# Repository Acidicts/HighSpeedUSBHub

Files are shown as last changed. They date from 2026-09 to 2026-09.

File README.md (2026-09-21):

# HighSpeedUSBHub

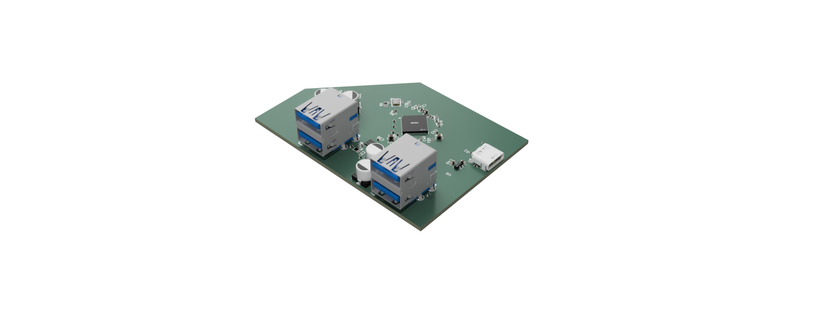
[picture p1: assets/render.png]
RENDER


I looked at an old USB 2.0 hub I made and though what if I could make a faster one? So I did(whether it works or not is another story). This started right after I discovered the [texas instruments](https://www.ti.com/) site via the guide for making a flight controller by @notaroomba.

This is a USB 3.1 hub which uses a usb 3.1 gen 2 upstream port to 4 usb 3.0 downstream ports via a [`TUSB8041`](https://www.ti.com/product/TUSB8041). Each USB stack (I used x2 stacked usb 3.0 ports as they were more compact, and they reminded me of the raspberry pi 4) is powered by a [`TPS2051B`](https://www.ti.com/product/TPS2051B) which is a power switch that has a power limit of around 1A per controller as I recall.

### Features
- 4 USB-A 3.0 downstream ports
- 1 USB-C 3.1 gen 2 upstream port
- Powered by the USB-C port (5V 3A)
- Each downstream port is limited to 1A of current and with equal load across each port, 0.5A per port.
- CRYSTAL 24MHz clock for the TUSB8041

<div class="inline-flex">
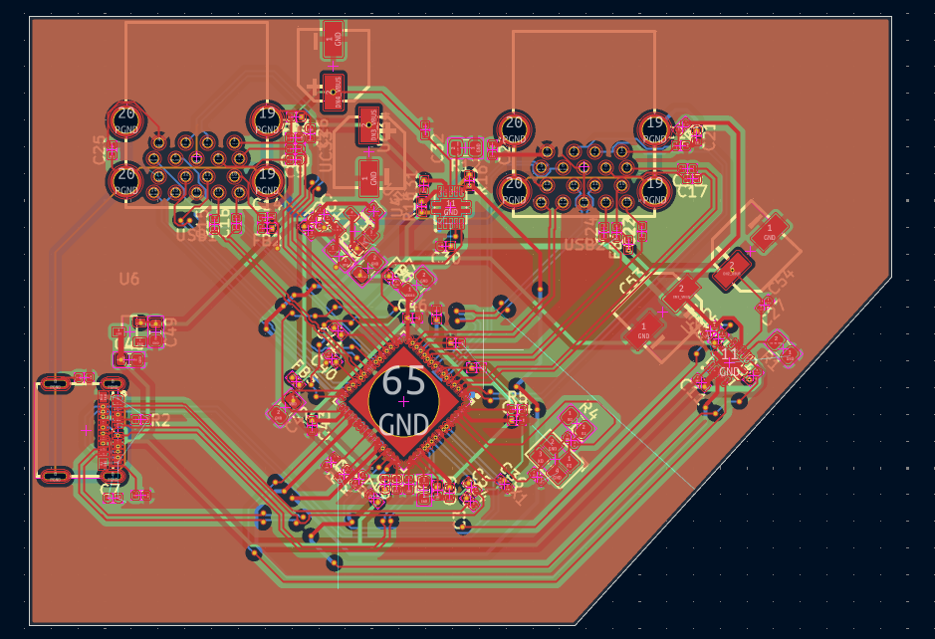
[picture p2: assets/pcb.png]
PCB

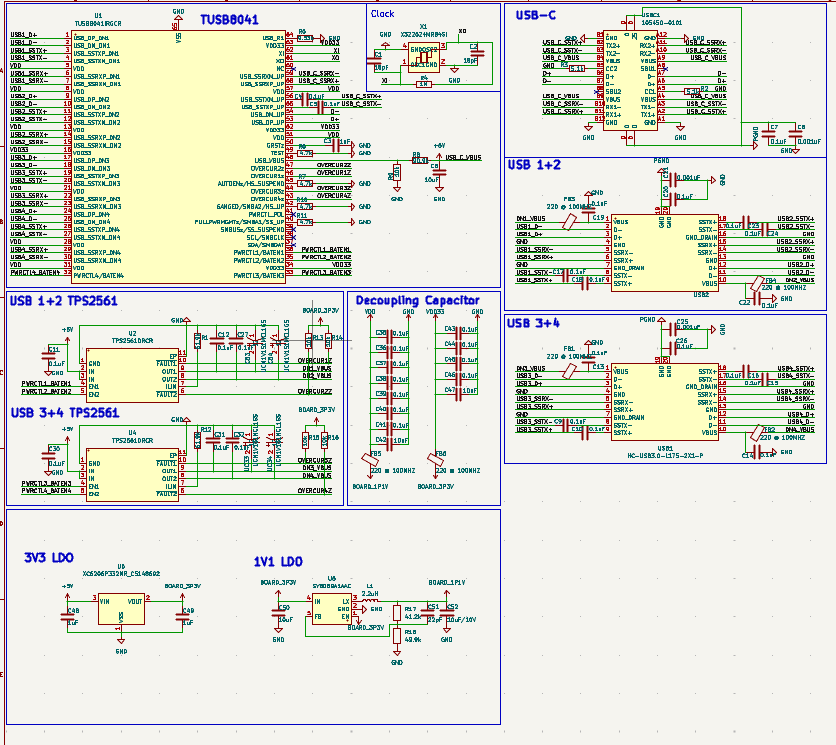
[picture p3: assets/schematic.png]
Schematic

</div>

### Case
Fusion 360 Link [here](https://a360.co/4czpJdL)
There are two parts of the case:
- The [Lid](case/Lid.stp)
- The [Base](case/Base.stp)
The lid has notches which slot into the base to hold it on using the power of friendship and friction.



### Getting Started
So ummm, how do I put this...

_*YOU PLUG IT IN*_

### Firmware
Sooo you won't believe this but it is just a usb hub, it is plug and play

### BOMs
- [BOM](BOM.csv)
- [PCB BOM](PCB_BOM.csv)

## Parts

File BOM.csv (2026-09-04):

What | Cost | Link
PCB | $7.00 | jlcpcb.com
PCBA | $84.89 | jlcpcb.com
Shipping | $11.88 | jlcpcb.com

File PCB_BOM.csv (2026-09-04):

Part Name, | Manufacturer/Type, | Designator, | Quantity, | Supplier, | Attrition Type, | LCSC Part#, | Unit Price, | Source
TUSB8041IRGCR, | Texas Instruments, | U1, | 2, | JLCPCB, | Extended, | C544686, | $4.0565, | [LCSC](https://www.lcsc.com/product-detail/C544686.html)
0402WGF4701TCE, | UNI-ROYAL (Uniroyal Elec), | R10,R11,R6,R7, | 8, | JLCPCB, | Basic, | C25900, | $0.0029, | [LCSC](https://www.lcsc.com/product-detail/C25900.html)
0402WGF1002TCE, | UNI-ROYAL (Uniroyal Elec), | R13,R14,R15,R16,R9, | 10, | JLCPCB, | Basic, | C25744, | $0.0031, | [LCSC](https://www.lcsc.com/product-detail/C25744.html)
XC6206P332MR, | HXY (MOSFET), | U6, | 10, | JLCPCB, | Extended, | C5148692, | $0.0182, | [LCSC](https://www.lcsc.com/product-detail/C5148692.html)
ARG05BTC6192, | Viking Tech, | R1,R12, | 8, | JLCPCB, | Extended, | C2984460, | $0.0290, | [LCSC](https://www.lcsc.com/product-detail/C2984460.html)
SMNR4020-2.2UH, | SXN (Shun Xiang Nuo Elec), | L1, | 6, | JLCPCB, | Extended, | C135262, | $0.0584, | [LCSC](https://www.lcsc.com/product-detail/C135262.html)
CR0402FF4122G, | LIZ Elec, | R17, | 20, | JLCPCB, | Extended, | C100420, | $0.0049, | [LCSC](https://www.lcsc.com/product-detail/C100420.html)
0805W8F1004T5E, | UNI-ROYAL (Uniroyal Elec), | R4, | 2, | JLCPCB, | Basic, | C17514, | $0.0047, | [LCSC](https://www.lcsc.com/product-detail/C17514.html)
CL05A106MQ5NUNC, | Samsung Electro-Mechanics, | C6, | 2, | JLCPCB, | Basic, | C15525, | $0.0256, | [LCSC](https://www.lcsc.com/product-detail/C15525.html)
0402CG220J500NT, | FH (Guangdong Fenghua Advanced Tech), | C51, | 2, | JLCPCB, | Basic, | C1555, | $0.0053, | [LCSC](https://www.lcsc.com/product-detail/C1555.html)
X322524MRB4SI, | YXC (Crystal Oscillators), | X1, | 6, | JLCPCB, | Extended, | C70571, | $0.1105, | [LCSC](https://www.lcsc.com/product-detail/C70571.html)
0402CG180J500NT, | FH (Guangdong Fenghua Advanced Tech), | C1,C2, | 4, | JLCPCB, | Basic, | C1549, | $0.0048, | [LCSC](https://www.lcsc.com/product-detail/C1549.html)
GRM21BR61H106KE43L, | Murata Electronics, | C42,C47,C50, | 6, | JLCPCB, | Basic, | C440198, | $0.2493, | [LCSC](https://www.lcsc.com/product-detail/C440198.html)
CL05B104KO5NNNC, | Samsung Electro-Mechanics, | C10,C11,C12,C13,C14,C15,C16,C17,C18,C19,C20,C22,C23,C24,C26,C27,C30,C31,C32,C35,C36,C37,C38,C39,C4,C40,C41,C43,C44,C45,C46,C5,C7,C9, | 68, | JLCPCB, | Basic, | C1525, | $0.0051, | [LCSC](https://www.lcsc.com/product-detail/C1525.html)
RC0402FR-0790K9L, | YAGEO, | R8, | 20, | JLCPCB, | Extended, | C163452, | $0.0039, | [LCSC](https://www.lcsc.com/product-detail/C163452.html)
0402WGF5101TCE, | UNI-ROYAL (Uniroyal Elec), | R2,R3, | 4, | JLCPCB, | Basic, | C25905, | $0.0026, | [LCSC](https://www.lcsc.com/product-detail/C25905.html)
UCM1V151MCL1GS, | Nichicon, | C53,C54,UC33,UC34, | 8, | JLCPCB, | Extended, | C729687, | $0.3816, | [LCSC](https://www.lcsc.com/product-detail/C729687.html)
BLM15PX221SN1D, | Murata Electronics, | FB1,FB2,FB3,FB4,FB5,FB6, | 22, | JLCPCB, | Extended, | C160973, | $0.0174, | [LCSC](https://www.lcsc.com/product-detail/C160973.html)
0402WGF9531TCE, | UNI-ROYAL (Uniroyal Elec), | R5, | 20, | JLCPCB, | Extended, | C96273, | $0.0026, | [LCSC](https://www.lcsc.com/product-detail/C96273.html)
TPS2561DRCR, | Texas Instruments, | U2,U4, | 4, | JLCPCB, | Extended, | C140303, | $1.4036, | [LCSC](https://www.lcsc.com/product-detail/C140303.html)
0402B102K500NT, | FH (Guangdong Fenghua Advanced Tech), | C21,C25,C8, | 6, | JLCPCB, | Basic, | C1523, | $0.0060, | [LCSC](https://www.lcsc.com/product-detail/C1523.html)
CL10A105KB8NNNC, | Samsung Electro-Mechanics, | C3,C48,C49, | 6, | JLCPCB, | Basic, | C15849, | $0.0058, | [LCSC](https://www.lcsc.com/product-detail/C15849.html)
0603WAF4992T5E, | UNI-ROYAL (Uniroyal Elec), | R18, | 2, | JLCPCB, | Basic, | C23184, | $0.0047, | [LCSC](https://www.lcsc.com/product-detail/C23184.html)
1054500101, | MOLEX, | USBC1, | 2, | JLCPCB, | Extended, | C134092, | $0.8399, | [LCSC](https://www.lcsc.com/product-detail/C134092.html)
SY8089A1AAC, | Silergy Corp, | U5, | 6, | JLCPCB, | Extended, | C479074, | $0.0879, | [LCSC](https://www.lcsc.com/product-detail/C479074.html)
CL05A106MP5NUNC, | Samsung Electro-Mechanics, | C52, | 20, | JLCPCB, | Extended, | C315248, | $0.0324, | [LCSC](https://www.lcsc.com/product-detail/C315248.html)
HC-USB3.0-L175-2X1-P, | Hong Cheng, | USB1,USB2, | 4, | JLCPCB, | Extended, | C7501881, | $0.3107, | [LCSC](https://www.lcsc.com/product-detail/C7501881.html)

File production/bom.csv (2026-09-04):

Designator | Footprint | Quantity | Value | LCSC Part #
C1, C2 | 0402 | 2 | 18pF
C10, C11, C12, C13, C14, C15, C16, C17, C18, C19, C20, C22, C23, C24, C26, C27, C30, C31, C32, C35, C36, C37, C38, C39, C4, C40, C41, C43, C44, C45, C46, C5, C7, C9 | 0402 | 34 | 0.1uF
C21, C25, C8 | 0402 | 3 | 0.001uF
C3, C48, C49 | 0603 | 3 | 1uF
C42, C47, C50 | 0805 | 3 | 10uF
C51 | 0402 | 1 | 22pF
C52 | 0402 | 1 | 10uF/10V
C53, C54, UC33, UC34 | CAP-SMD_L6.6-W6.6 | 4 | UCM1V151MCL1GS | C729687
C6 | 0402 | 1 | 10uF
FB1, FB2, FB3, FB4, FB5, FB6 | 0402 | 6 | 220 @ 100MHZ
L1 | L_Coilcraft_0403HQ_1008Metric | 1 | 2.2uH
R1, R12 | 0805 | 2 | 61.9k
R10, R11, R6, R7 | 0402 | 4 | 4.7k
R13, R14, R15, R16, R9 | 0402 | 5 | 10k
R17 | 0402 | 1 | 41.2k
R18 | 0603 | 1 | 49.9k
R2, R3 | 0402 | 2 | 5.1k
R4 | 0805 | 1 | 1M
R5 | 0402 | 1 | 9.53k
R8 | 0402 | 1 | 90.9k
U1 | QFN-64_L9.0-W9.0-P0.50-BL-EP7.2 | 1 | TUSB8041IRGCR | C544686
U2, U4 | VSON-10_L3.0-W3.0-P0.50-TL-EP_TPS62410DRCR | 2 | TPS2561DRCR | C140303
U5 | TSOT-23-5_L2.9-W1.6-P0.95-LS2.8-BR | 1 | SY8089A1AAC | C479074
U6 | SOT-23-3_L2.9-W1.3-P1.90-LS2.4-BR | 1 | XC6206P332MR_C5148692 | C5148692
USB1, USB2 | USB-A-TH_H181-AF2R06-12ALCR | 2 | HC-USB3.0-L175-2X1-P | C7501881
USBC1 | USB-C-SMD_TYPE-C-USB-18 | 1 | 105450-0101 | C134092
X1 | CRYSTAL-SMD_4P-L3.2-W2.5-BL-2 | 1 | X322524MRB4SI | C70571

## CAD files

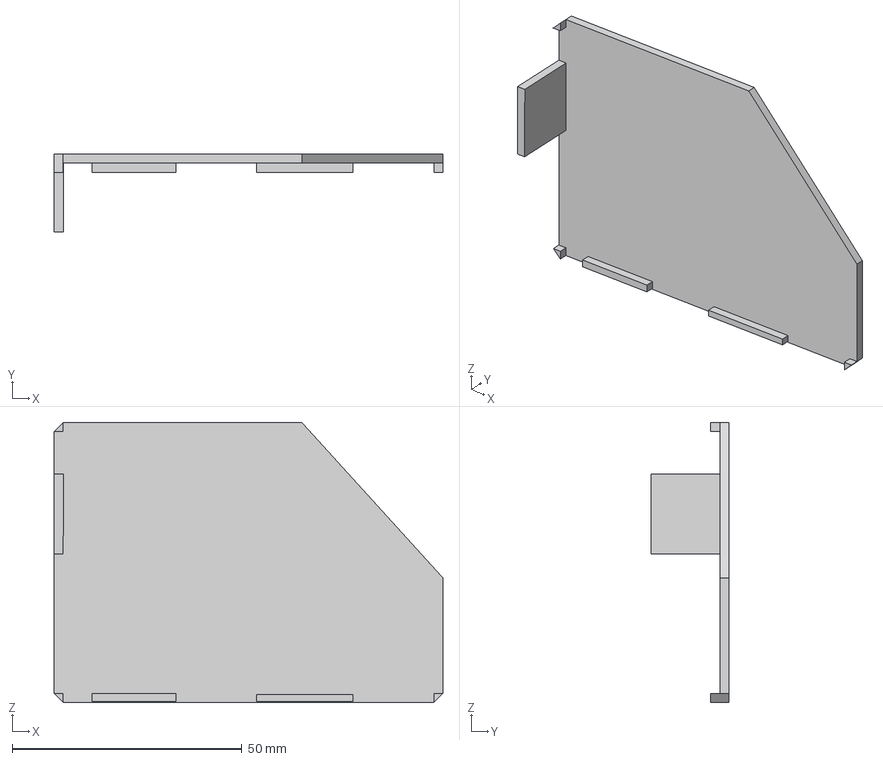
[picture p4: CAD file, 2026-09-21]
case/Lid.stp
84.6 x 17.0 x 61.0 mm

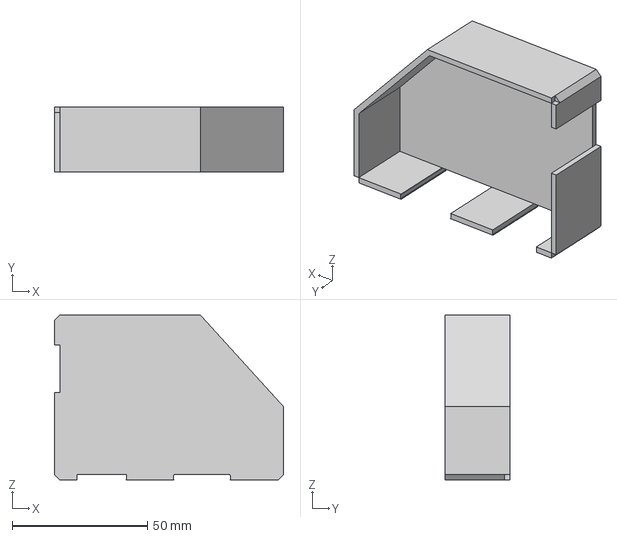
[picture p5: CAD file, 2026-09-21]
case/Base.stp
84.6 x 24.0 x 61.0 mm

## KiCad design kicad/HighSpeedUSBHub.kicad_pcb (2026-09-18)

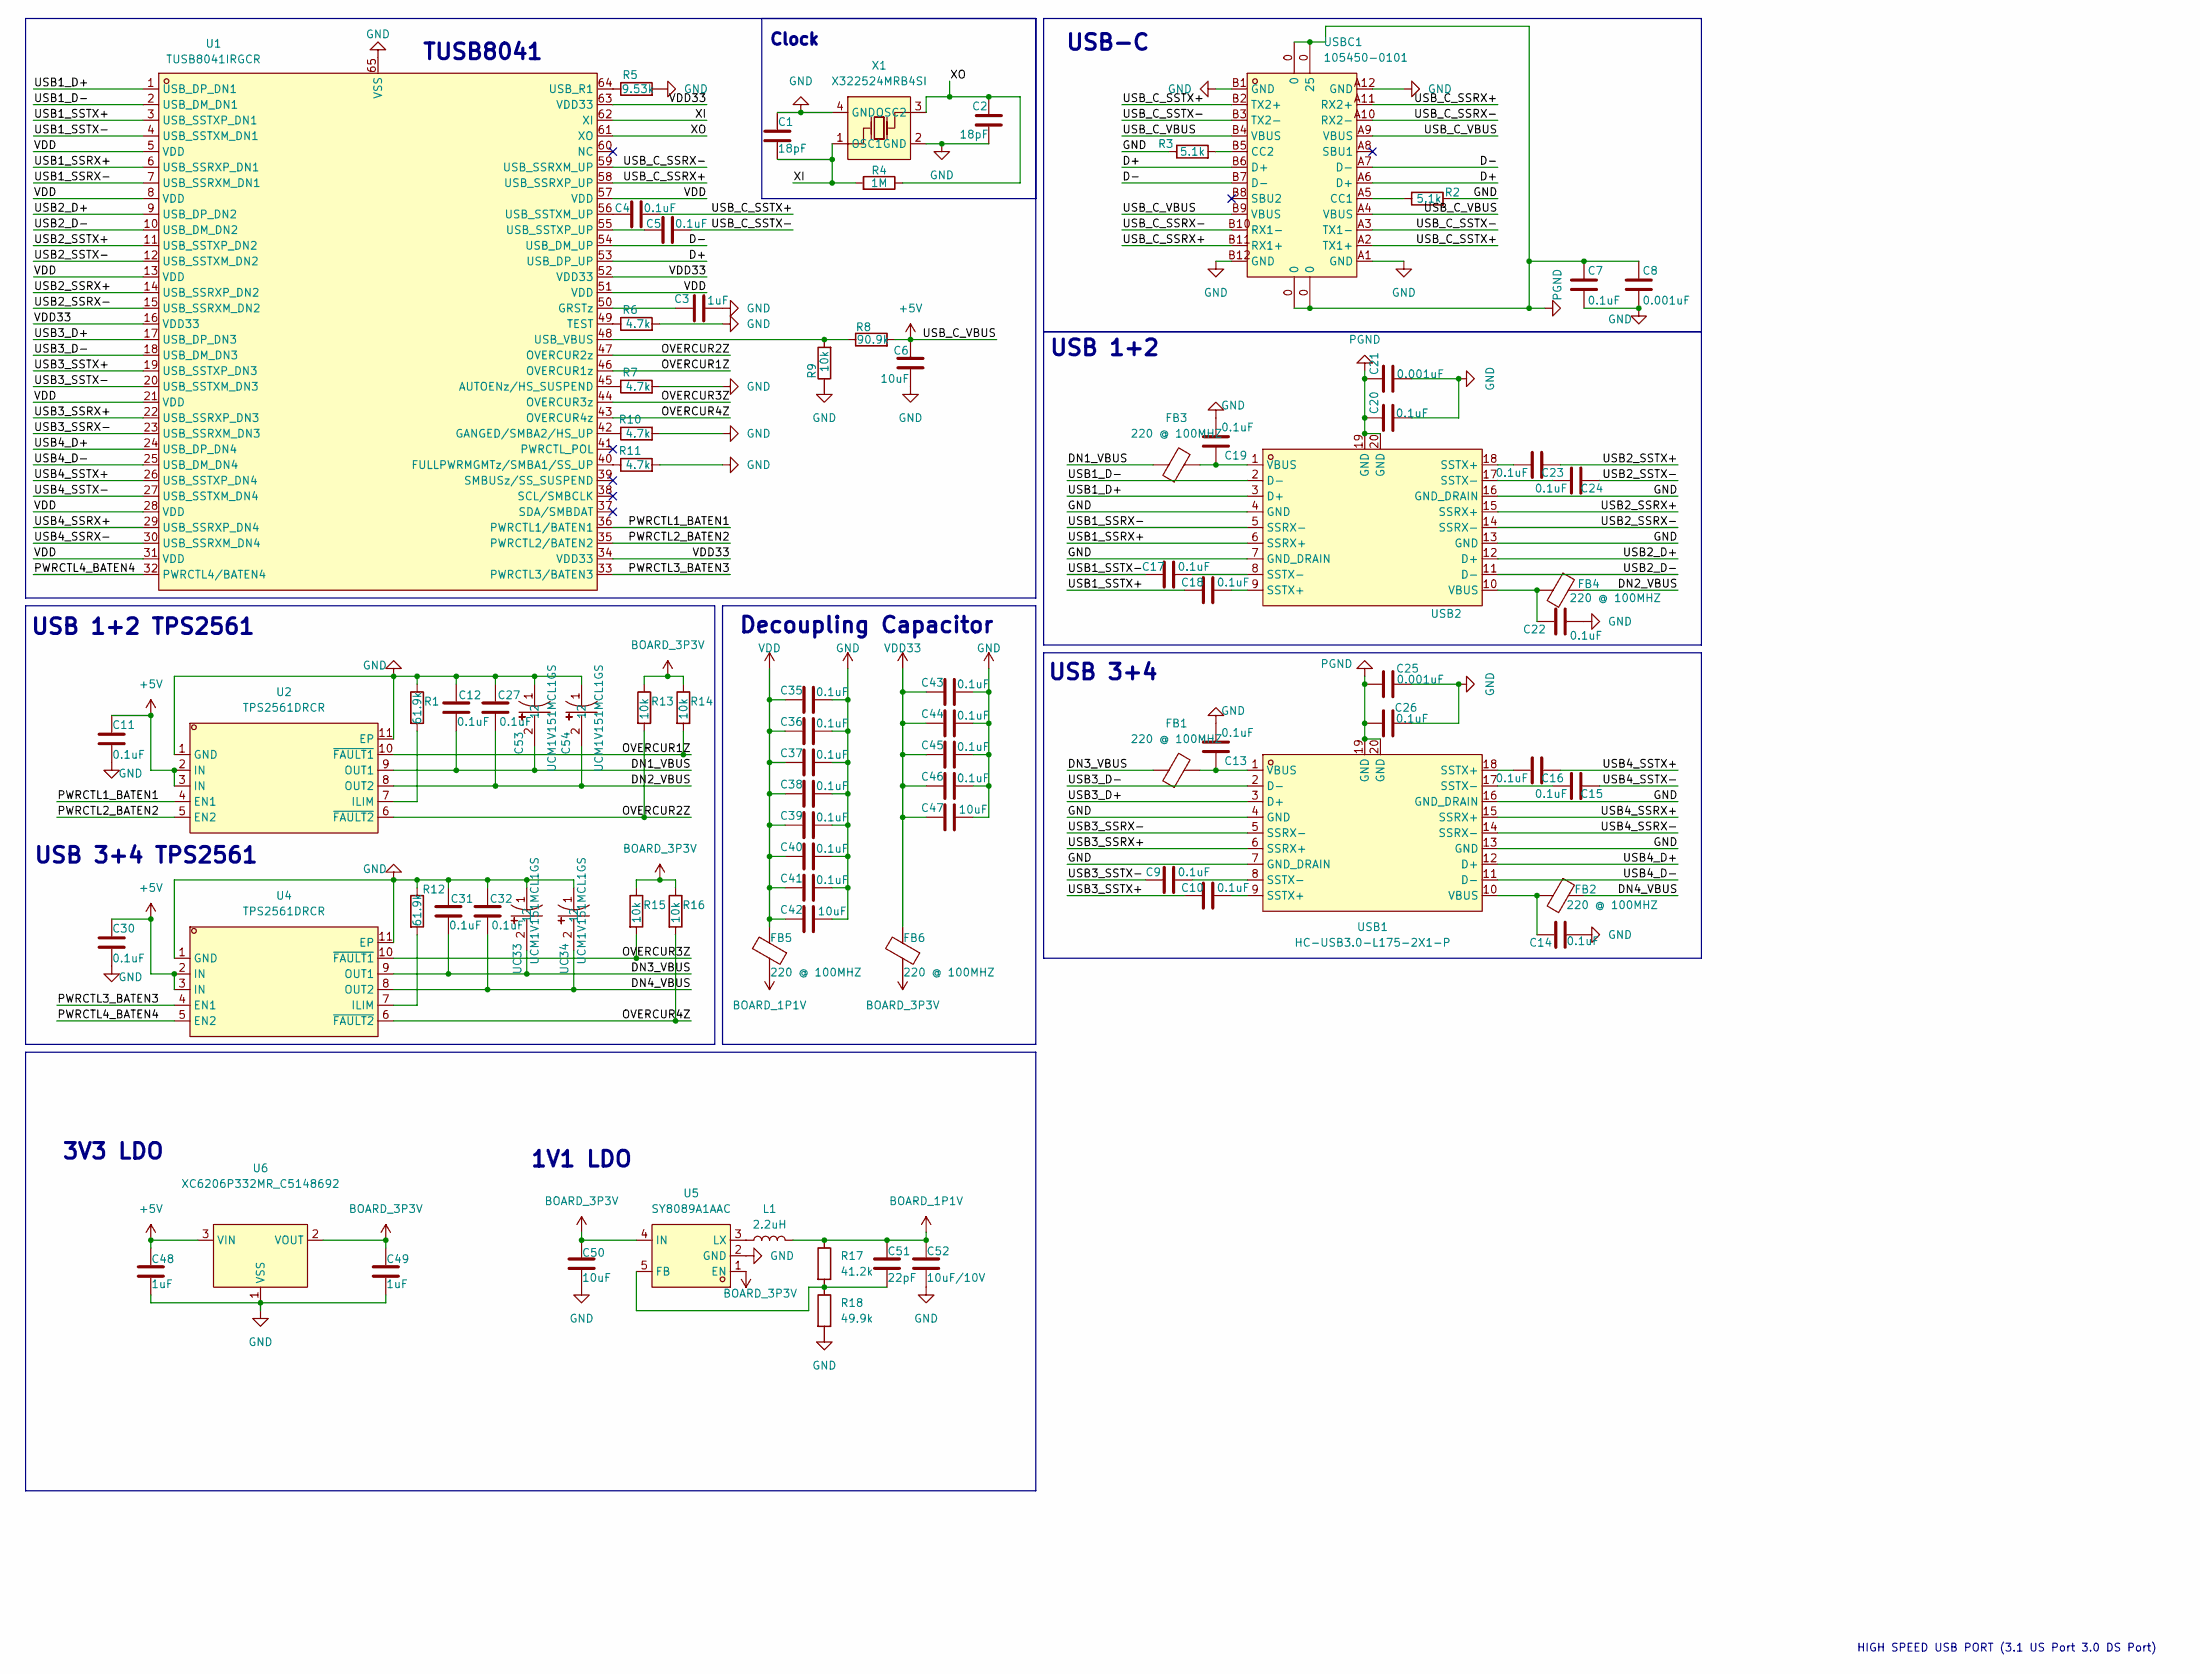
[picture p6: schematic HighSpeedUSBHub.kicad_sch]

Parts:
C1, C2: 18pF; C_0402_1005Metric
C3, C48, C49: 1uF; C_0603_1608Metric
C4, C5, C7, C9, C10, C11, C12, C13, C14, C15, C16, C17, C18, C19, C20, C22, C23, C24, C26, C27, C30, C31, C32, C35, C36, C37, C38, C39, C40, C41, C43, C44, C45, C46: 0.1uF; C_0402_1005Metric
C6: 10uF; C_0402_1005Metric
C8, C21, C25: 0.001uF; C_0402_1005Metric
C42, C47, C50: 10uF; C_0805_2012Metric
C51: 22pF; C_0402_1005Metric
C52: 10uF/10V; C_0402_1005Metric
C53, C54: UCM1V151MCL1GS; CAP-SMD_L6.6-W6.6; MPN UCM1V151MCL1GS; LCSC Part C729687
FB1, FB2, FB3, FB4, FB5, FB6: 220 @ 100MHZ; C_0402_1005Metric
L1: 2.2uH; L_Coilcraft_0403HQ_1008Metric
R1, R12: 61.9k; R_0805_2012Metric
R2, R3: 5.1k; R_0402_1005Metric
R4: 1M; R_0805_2012Metric
R5: 9.53k; R_0402_1005Metric
R6, R7, R10, R11: 4.7k; R_0402_1005Metric
R8: 90.9k; R_0402_1005Metric
R9, R13, R14, R15, R16: 10k; R_0402_1005Metric
R17: 41.2k; R_0402_1005Metric
R18: 49.9k; R_0603_1608Metric
U1: TUSB8041IRGCR; QFN-64_L9.0-W9.0-P0.50-BL-EP7.2; MPN TUSB8041IRGCR; LCSC Part C544686
U2, U4: TPS2561DRCR; VSON-10_L3.0-W3.0-P0.50-TL-EP_TPS62410DRCR; MPN TPS2561DRCR; LCSC Part C140303
U5: SY8089A1AAC; TSOT-23-5_L2.9-W1.6-P0.95-LS2.8-BR; MPN SY8089A1AAC; LCSC Part C479074
U6: XC6206P332MR_C5148692; SOT-23-3_L2.9-W1.3-P1.90-LS2.4-BR; MPN XC6206P332MR; LCSC Part C5148692
UC33, UC34: UCM1V151MCL1GS; CAP-SMD_L6.6-W6.6; MPN UCM1V151MCL1GS; LCSC Part C729687
USB1, USB2: HC-USB3.0-L175-2X1-P; USB-A-TH_H181-AF2R06-12ALCR; MPN HC-USB3.0-L175-2X1-P; LCSC Part C7501881
USBC1: 105450-0101; USB-C-SMD_TYPE-C-USB-18; MPN 1054500101; LCSC Part C134092
X1: X322524MRB4SI; CRYSTAL-SMD_4P-L3.2-W2.5-BL-2; MPN X322524MRB4SI; LCSC Part C70571

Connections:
+5V: C6.2, C11.1, C30.1, C48.1, R8.2, U2.2 (IN), U2.3 (IN), U4.2 (IN), U4.3 (IN), U6.3 (VIN), USBC1.A4 (VBUS), USBC1.A9 (VBUS), USBC1.B4 (VBUS), USBC1.B9 (VBUS)
/D+: U1.53 (USB_DP_UP), USBC1.A6 (D+), USBC1.B6 (D+)
/D-: U1.54 (USB_DM_UP), USBC1.A7 (D-), USBC1.B7 (D-)
/DN1_VBUS: C12.2, C53.2, FB3.1, U2.9 (OUT1)
/DN2_VBUS: C27.2, C54.2, FB4.1, U2.8 (OUT2)
/DN3_VBUS: C31.2, FB1.1, U4.9 (OUT1), UC33.2
/DN4_VBUS: C32.2, FB2.1, U4.8 (OUT2), UC34.2
/OVERCUR1Z: R14.2, U1.46 (OVERCUR1z), U2.10 (~FAULT1)
/OVERCUR2Z: R13.2, U1.47 (OVERCUR2z), U2.6 (~FAULT2)
/OVERCUR3Z: R15.2, U1.44 (OVERCUR3z), U4.10 (~FAULT1)
/OVERCUR4Z: R16.2, U1.43 (OVERCUR4z), U4.6 (~FAULT2)
/PWRCTL1_BATEN1: U1.36 (PWRCTL1/BATEN1), U2.4 (EN1)
/PWRCTL2_BATEN2: U1.35 (PWRCTL2/BATEN2), U2.5 (EN2)
/PWRCTL3_BATEN3: U1.33 (PWRCTL3/BATEN3), U4.4 (EN1)
/PWRCTL4_BATEN4: U1.32 (PWRCTL4/BATEN4), U4.5 (EN2)
/USB1_D+: U1.1 (USB_DP_DN1), USB2.3 (D+)
/USB1_D-: U1.2 (USB_DM_DN1), USB2.2 (D-)
/USB1_SSRX+: U1.6 (USB_SSRXP_DN1), USB2.6 (SSRX+)
/USB1_SSRX-: U1.7 (USB_SSRXM_DN1), USB2.5 (SSRX-)
/USB1_SSTX+: C18.1, U1.3 (USB_SSTXP_DN1)
/USB1_SSTX-: C17.1, U1.4 (USB_SSTXM_DN1)
/USB2_D+: U1.9 (USB_DP_DN2), USB2.12 (D+)
/USB2_D-: U1.10 (USB_DM_DN2), USB2.11 (D-)
/USB2_SSRX+: U1.14 (USB_SSRXP_DN2), USB2.15 (SSRX+)
/USB2_SSRX-: U1.15 (USB_SSRXM_DN2), USB2.14 (SSRX-)
/USB2_SSTX+: C23.1, U1.11 (USB_SSTXP_DN2)
/USB2_SSTX-: C24.1, U1.12 (USB_SSTXM_DN2)
/USB3_D+: U1.17 (USB_DP_DN3), USB1.3 (D+)
/USB3_D-: U1.18 (USB_DM_DN3), USB1.2 (D-)
/USB3_SSRX+: U1.22 (USB_SSRXP_DN3), USB1.6 (SSRX+)
/USB3_SSRX-: U1.23 (USB_SSRXM_DN3), USB1.5 (SSRX-)
/USB3_SSTX+: C10.1, U1.19 (USB_SSTXP_DN3)
/USB3_SSTX-: C9.1, U1.20 (USB_SSTXM_DN3)
/USB4_D+: U1.24 (USB_DP_DN4), USB1.12 (D+)
/USB4_D-: U1.25 (USB_DM_DN4), USB1.11 (D-)
/USB4_SSRX+: U1.29 (USB_SSRXP_DN4), USB1.15 (SSRX+)
/USB4_SSRX-: U1.30 (USB_SSRXM_DN4), USB1.14 (SSRX-)
/USB4_SSTX+: C16.1, U1.26 (USB_SSTXP_DN4)
/USB4_SSTX-: C15.1, U1.27 (USB_SSTXM_DN4)
/USB_C_SSRX+: U1.58 (USB_SSRXP_UP), USBC1.A11 (RX2+), USBC1.B11 (RX1+)
/USB_C_SSRX-: U1.59 (USB_SSRXM_UP), USBC1.A10 (RX2-), USBC1.B10 (RX1-)
/USB_C_SSTX+: C4.2, USBC1.A2 (TX1+), USBC1.B2 (TX2+)
/USB_C_SSTX-: C5.2, USBC1.A3 (TX1-), USBC1.B3 (TX2-)
/XI: C1.2, R4.2, U1.62 (XI), X1.1 (OSC1)
/XO: C2.1, R4.1, U1.61 (XO), X1.3 (OSC2)
BOARD_1P1V: C51.1, C52.1, FB5.1, L1.2, R17.1
BOARD_3P3V: C49.1, C50.1, FB6.1, R13.1, R14.1, R15.1, R16.1, U5.1 (EN), U5.4 (IN), U6.2 (VOUT)
GND: C1.1, C2.2, C3.2, C6.1, C7.2, C8.2, C11.2, C12.1, C13.2, C14.2, C19.2, C20.2, C21.2, C22.2, C25.2, C26.2, C27.1, C30.2, C31.1, C32.1, C35.2, C36.2, C37.2, C38.2, C39.2, C40.2, C41.2, C42.2, C43.2, C44.2, C45.2, C46.2, C47.2, C48.2, C49.2, C50.2, C52.2, C53.1, C54.1, R1.1, R2.2, R3.1, R5.2, R6.2, R7.2, R9.1, R10.2, R11.2, R12.1, R18.2, U1.65 (VSS), U2.1 (GND), U2.11 (EP), U4.1 (GND), U4.11 (EP), U5.2 (GND), U6.1 (VSS), UC33.1, UC34.1, USB1.4 (GND), USB1.7 (GND_DRAIN), USB1.13 (GND), USB1.16 (GND_DRAIN), USB2.4 (GND), USB2.7 (GND_DRAIN), USB2.13 (GND), USB2.16 (GND_DRAIN), USBC1.A1 (GND), USBC1.A12 (GND), USBC1.B1 (GND), USBC1.B12 (GND), X1.2 (GND), X1.4 (GND)
unnamed: C9.2, USB1.8 (SSTX-)
unnamed: C10.2, USB1.9 (SSTX+)
unnamed: C13.1, FB1.2, USB1.1 (VBUS)
unnamed: C14.1, FB2.2, USB1.10 (VBUS)
unnamed: C15.2, USB1.17 (SSTX-)
unnamed: C16.2, USB1.18 (SSTX+)
unnamed: C17.2, USB2.8 (SSTX-)
unnamed: C18.2, USB2.9 (SSTX+)
unnamed: C19.1, FB3.2, USB2.1 (VBUS)
unnamed: C22.1, FB4.2, USB2.10 (VBUS)
unnamed: C23.2, USB2.18 (SSTX+)
unnamed: C24.2, USB2.17 (SSTX-)
unnamed: R7.1, U1.45 (AUTOENz/HS_SUSPEND)
unnamed: R11.1, U1.40 (FULLPWRMGMTz/SMBA1/SS_UP)
unnamed: R10.1, U1.42 (GANGED/SMBA2/HS_UP)
unnamed: C3.1, U1.50 (GRSTz)
unnamed: R6.1, U1.49 (TEST)
unnamed: R5.1, U1.64 (USB_R1)
unnamed: C4.1, U1.56 (USB_SSTXM_UP)
unnamed: C5.1, U1.55 (USB_SSTXP_UP)
unnamed: R8.1, R9.2, U1.48 (USB_VBUS)
unnamed: R1.2, U2.7 (ILIM)
unnamed: R12.2, U4.7 (ILIM)
unnamed: C51.2, R17.2, R18.1, U5.5 (FB)
unnamed: L1.1, U5.3 (LX)
unnamed: R2.1, USBC1.A5 (CC1)
unnamed: R3.2, USBC1.B5 (CC2)
PGND: C7.1, C8.1, C20.1, C21.1, C25.1, C26.1, USB1.19 (GND), USB1.20 (GND), USB2.19 (GND), USB2.20 (GND), USBC1.0
VDD: C35.1, C36.1, C37.1, C38.1, C39.1, C40.1, C41.1, C42.1, FB5.2, U1.5 (VDD), U1.8 (VDD), U1.13 (VDD), U1.21 (VDD), U1.28 (VDD), U1.31 (VDD), U1.51 (VDD), U1.57 (VDD)
VDD33: C43.1, C44.1, C45.1, C46.1, C47.1, FB6.2, U1.16 (VDD33), U1.34 (VDD33), U1.52 (VDD33), U1.63 (VDD33)

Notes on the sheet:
3V3 LDO
TUSB8041
USB 1+2 TPS2561
USB 3+4 TPS2561
1V1 LDO
USB 1+2
USB 3+4
Clock
Decoupling Capacitor
USB-C
HIGH SPEED USB PORT (3.1 US Port 3.0 DS Port)

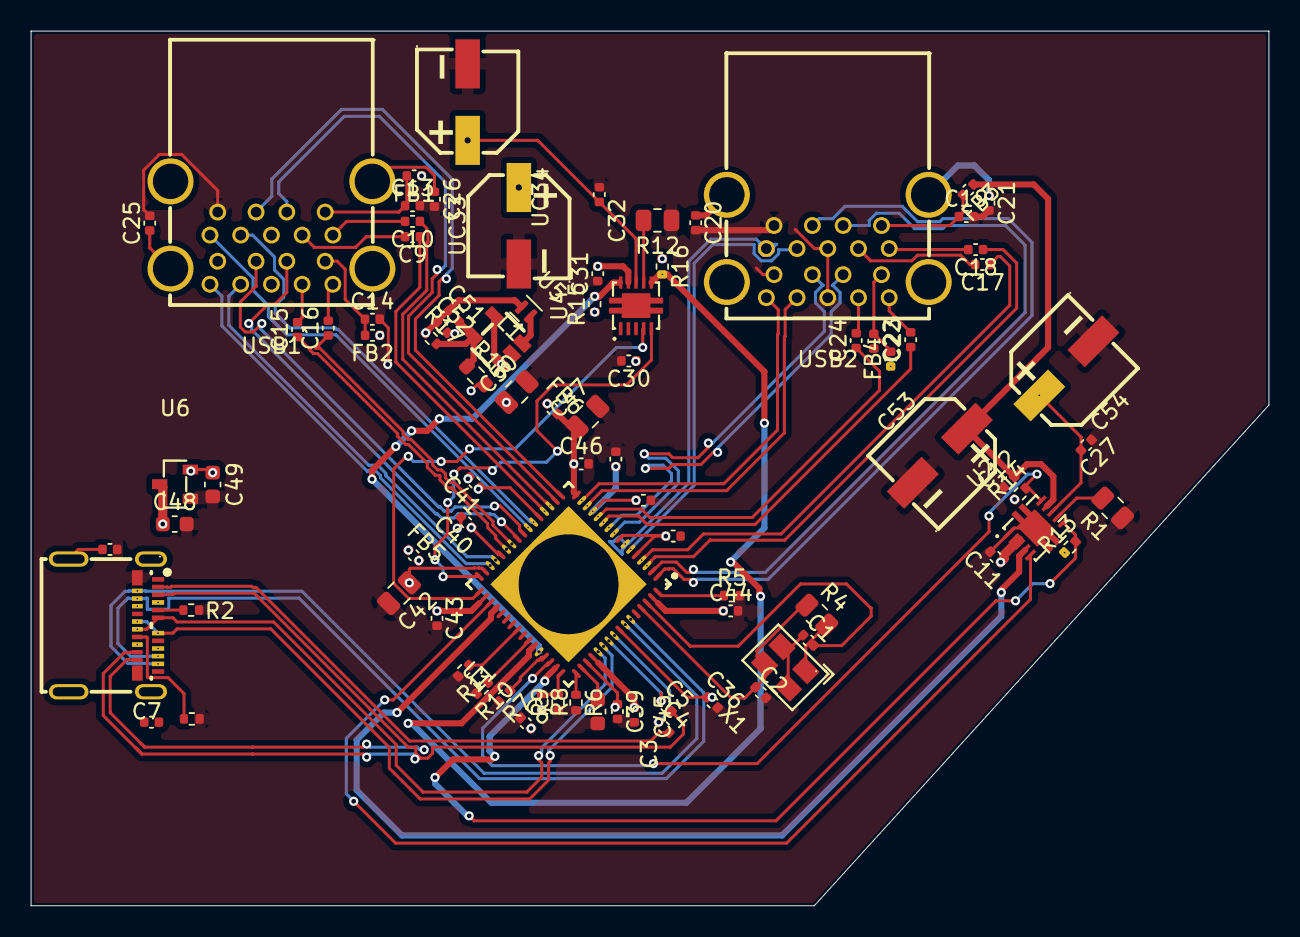
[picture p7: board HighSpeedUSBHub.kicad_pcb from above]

Board: 4 copper layers, 80.6 x 57.0 mm, 86 parts (0 on the bottom side), 78 nets.
